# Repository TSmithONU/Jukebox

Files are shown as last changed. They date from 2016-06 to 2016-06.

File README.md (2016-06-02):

# Jukebox
This is the code and diagram to the Blue Jukebox located in COSI's Progress exhibit. Blue runs on an Arduino Mega and an Adafruit VS1053 Breakout board. This exhibit allows users to select a track number, and the corresponding track is played. To accomplish this, the mega reads in button presses from the button array on the front of the jukebox. The Mega then uses serial communication to begin playback of the track. Relay control was added to control the button latching and record spinning during playback. There is also a reset button that ends playback and resets the VS1053.

This software is designed to work with any Mega and can be costomized to playback any mp3 file.

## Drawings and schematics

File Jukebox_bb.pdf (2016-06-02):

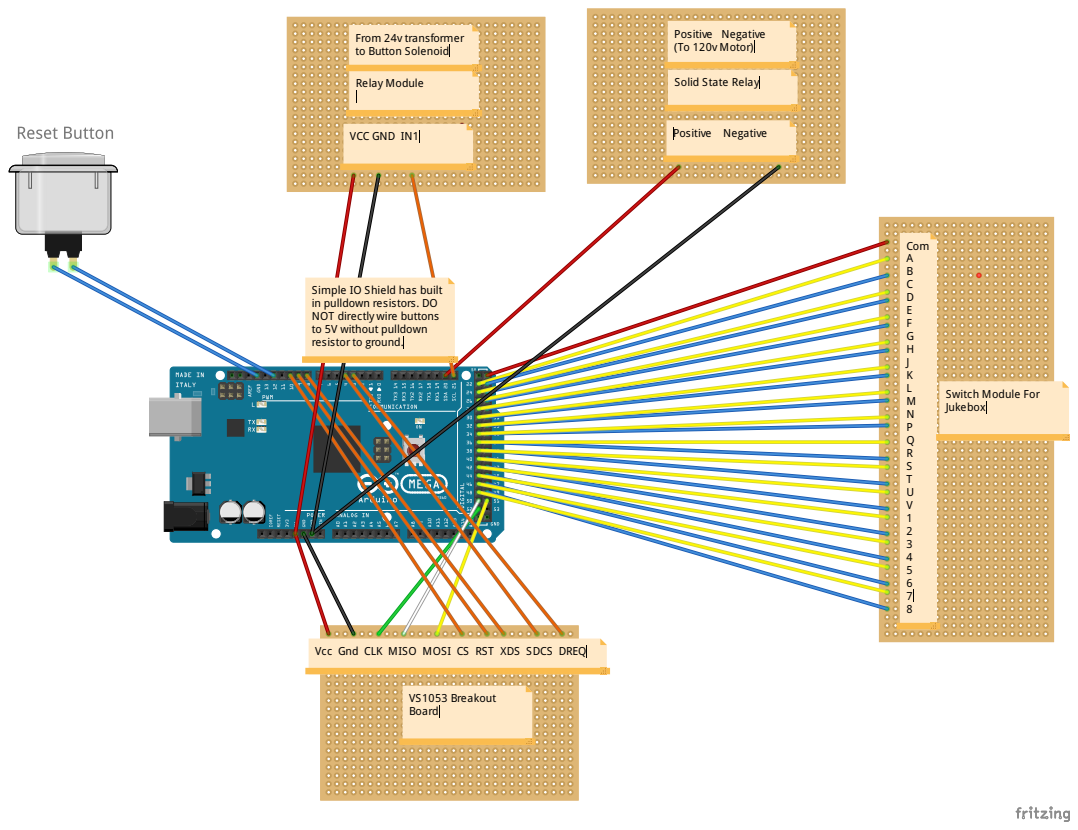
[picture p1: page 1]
Com A B C D E F G H J K L M N P Q R S T U V 1 2 3 4 5 6 7 8; VS1053 Breakout Board; Positive Negative; Positive Negative (To 120v Motor); Relay Module; VCC GND IN1

From 24v transformer
to Button Solenoid

Solid State Relay

Simple IO Shield has built
in pulldown resistors. DO
NOT directlywire buttons
to 5V without pulldown
resistorto ground.

Switch Module For
Jukebox

Vcc Gnd CLK MISO MOSI CS RST XDS SDCS DREQ

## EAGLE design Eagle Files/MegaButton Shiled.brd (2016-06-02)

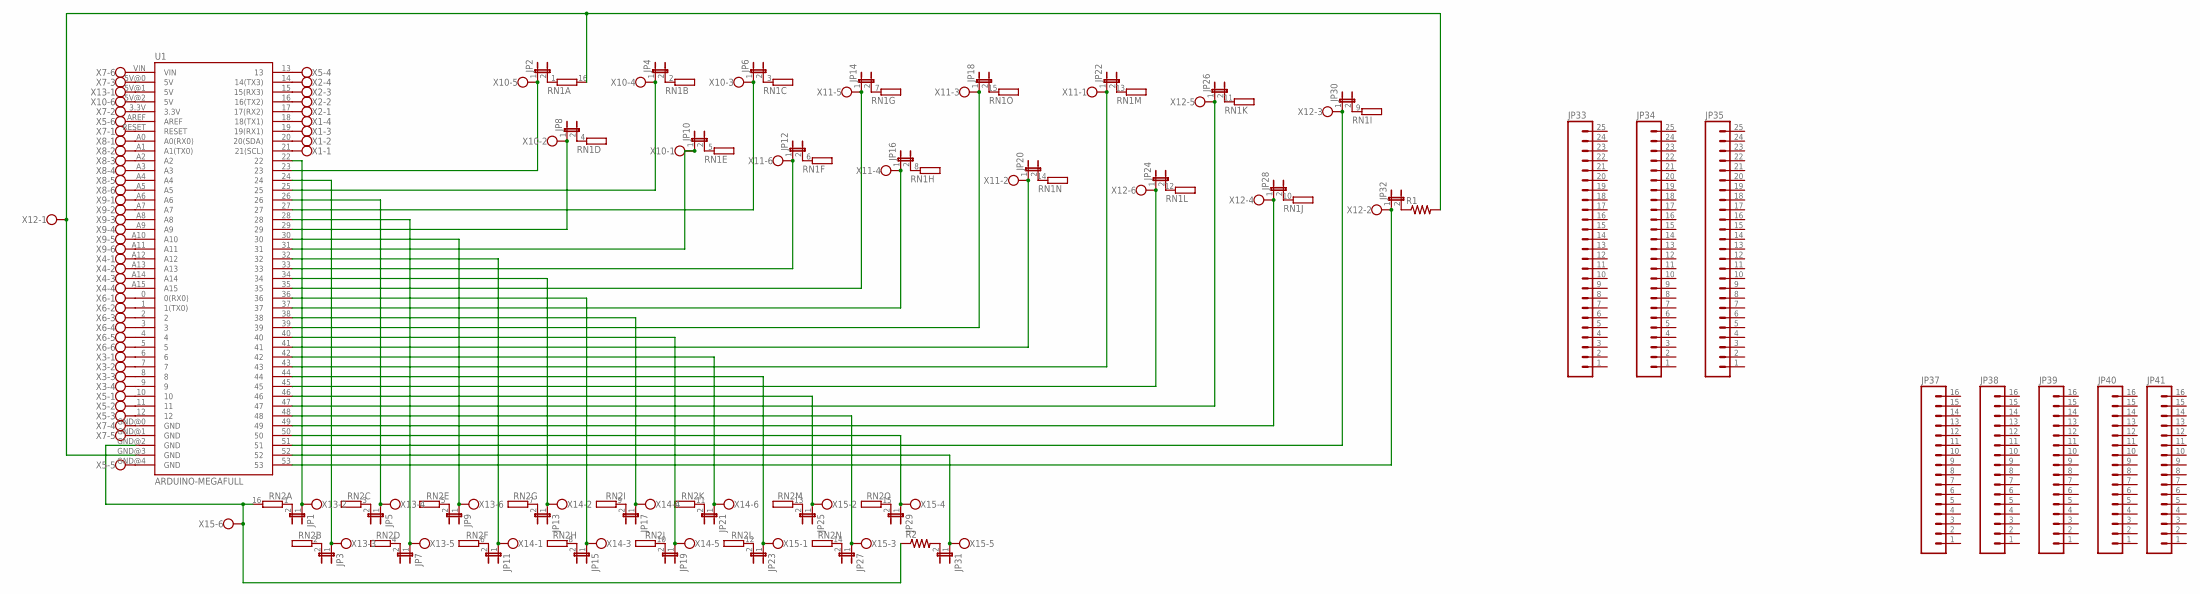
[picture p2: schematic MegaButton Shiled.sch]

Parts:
JP1, JP2, JP3, JP4, JP5, JP6, JP7, JP8, JP9, JP10, JP11, JP12, JP13, JP14, JP15, JP16, JP17, JP18, JP19, JP20, JP21, JP22, JP23, JP24, JP25, JP26, JP27, JP28, JP29, JP30, JP31, JP32: JP1E; JP1
JP33, JP34, JP35: M25PTH; 1X25
JP37, JP38, JP39, JP40, JP41: M16PTH; 1X16
R1, R2: R-US_0204/5; 0204/5
RN1, RN2: E15R; DIL16
U1: ARDUINO-MEGAFULL; ARDUINO_MEGA
X1, X2, X3, X4: W237-4
X5, X6, X7: W237-136
X8, X9, X10, X11, X12, X13, X14, X15: W237-6

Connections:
unnamed: U1.18 (18(TX1)), X1.4
unnamed: U1.19 (19(RX1)), X1.3
unnamed: U1.20 (20(SDA)), X1.2
unnamed: U1.21 (21(SCL)), X1.1
unnamed: U1.14 (14(TX3)), X2.4
unnamed: U1.15 (15(RX3)), X2.3
unnamed: U1.16 (16(TX2)), X2.2
unnamed: U1.17 (17(RX2)), X2.1
unnamed: U1.0 (0(RX0)), X6.1
unnamed: U1.1 (1(TX0)), X6.2
unnamed: U1.2, X6.3
unnamed: U1.3, X6.4
unnamed: U1.4, X6.5
unnamed: U1.5, X6.6
unnamed: U1.6, X3.1
unnamed: U1.7, X3.2
unnamed: U1.8, X3.3
unnamed: U1.9, X3.4
unnamed: U1.10, X5.1
unnamed: U1.11, X5.2
unnamed: U1.12, X5.3
unnamed: U1.13, X5.4
unnamed: U1.GND@4 (GND), X5.5
unnamed: U1.AREF, X5.6
unnamed: U1.RESET, X7.1
unnamed: U1.3.3V, X7.2
unnamed: U1.5V@0 (5V), X7.3
unnamed: U1.GND@0 (GND), X7.4
unnamed: U1.GND@1 (GND), X7.5
unnamed: U1.VIN, X7.6
unnamed: U1.A0 (A0(RX0)), X8.1
unnamed: U1.A1 (A1(TX0)), X8.2
unnamed: U1.A2, X8.3
unnamed: U1.A3, X8.4
unnamed: U1.A4, X8.5
unnamed: U1.A5, X8.6
unnamed: U1.A6, X9.1
unnamed: U1.A7, X9.2
unnamed: U1.A8, X9.3
unnamed: U1.A9, X9.4
unnamed: U1.A10, X9.5
unnamed: U1.A11, X9.6
unnamed: U1.A12, X4.1
unnamed: U1.A13, X4.2
unnamed: U1.A14, X4.3
unnamed: U1.A15, X4.4
unnamed: U1.5V@2 (5V), X10.6
unnamed: JP2.2, RN1.1
unnamed: JP2.1, U1.23, X10.5
unnamed: JP1.1, U1.22, X13.2
unnamed: JP4.1, U1.25, X10.4
unnamed: JP4.2, RN1.2 (1)
unnamed: JP6.1, U1.27, X10.3
unnamed: JP6.2, RN1.3 (1)
unnamed: JP8.1, U1.29, X10.2
unnamed: JP8.2, RN1.4 (1)
unnamed: JP10.1, U1.31, X10.1
unnamed: JP10.2, RN1.5 (1)
unnamed: JP12.1, U1.33, X11.6
unnamed: JP12.2, RN1.6 (1)
unnamed: JP14.2, RN1.7 (1)
unnamed: JP14.1, U1.35, X11.5
unnamed: JP16.2, RN1.8 (1)
unnamed: JP16.1, U1.37, X11.4
unnamed: JP18.2, RN1.15 (1)
unnamed: JP18.1, U1.39, X11.3
unnamed: JP20.1, U1.41, X11.2
unnamed: JP20.2, RN1.14 (1)
unnamed: JP22.1, U1.43, X11.1
unnamed: JP22.2, RN1.13 (1)
unnamed: JP24.1, U1.45, X12.6
unnamed: JP24.2, RN1.12 (1)
unnamed: JP26.2, RN1.11 (1)
unnamed: JP26.1, U1.47, X12.5
unnamed: JP28.2, RN1.10 (1)
unnamed: JP28.1, U1.49, X12.4
unnamed: JP30.2, RN1.9 (1)
unnamed: JP30.1, U1.51, X12.3
unnamed: JP32.1, U1.53, X12.2
unnamed: JP32.2, R1.1
unnamed: JP1.2, RN2.1
unnamed: U1.5V@1 (5V), X13.1
unnamed: JP3.2, RN2.2 (1)
unnamed: JP3.1, U1.24, X13.3
unnamed: JP5.2, RN2.3 (1)
unnamed: JP5.1, U1.26, X13.4
unnamed: JP7.2, RN2.4 (1)
unnamed: JP7.1, U1.28, X13.5
unnamed: JP9.2, RN2.5 (1)
unnamed: JP9.1, U1.30, X13.6
unnamed: JP11.2, RN2.6 (1)
unnamed: JP11.1, U1.32, X14.1
unnamed: JP13.2, RN2.7 (1)
unnamed: JP13.1, U1.34, X14.2
unnamed: JP15.2, RN2.8 (1)
unnamed: JP15.1, U1.36, X14.3
unnamed: JP17.2, RN2.9 (1)
unnamed: JP17.1, U1.38, X14.4
unnamed: JP19.2, RN2.10 (1)
unnamed: JP19.1, U1.40, X14.5
unnamed: JP21.2, RN2.11 (1)
unnamed: JP21.1, U1.42, X14.6
unnamed: JP23.2, RN2.12 (1)
unnamed: JP23.1, U1.44, X15.1
unnamed: JP25.2, RN2.13 (1)
unnamed: JP25.1, U1.46, X15.2
unnamed: R1.2, RN1.16 (2), U1.GND@3 (GND), X12.1
unnamed: JP27.2, RN2.14 (1)
unnamed: JP27.1, U1.48, X15.3
unnamed: JP29.2, RN2.15 (1)
unnamed: JP29.1, U1.50, X15.4
unnamed: JP31.2, R2.2
unnamed: JP31.1, U1.52, X15.5
unnamed: R2.1, RN2.16 (2), U1.GND@2 (GND), X15.6

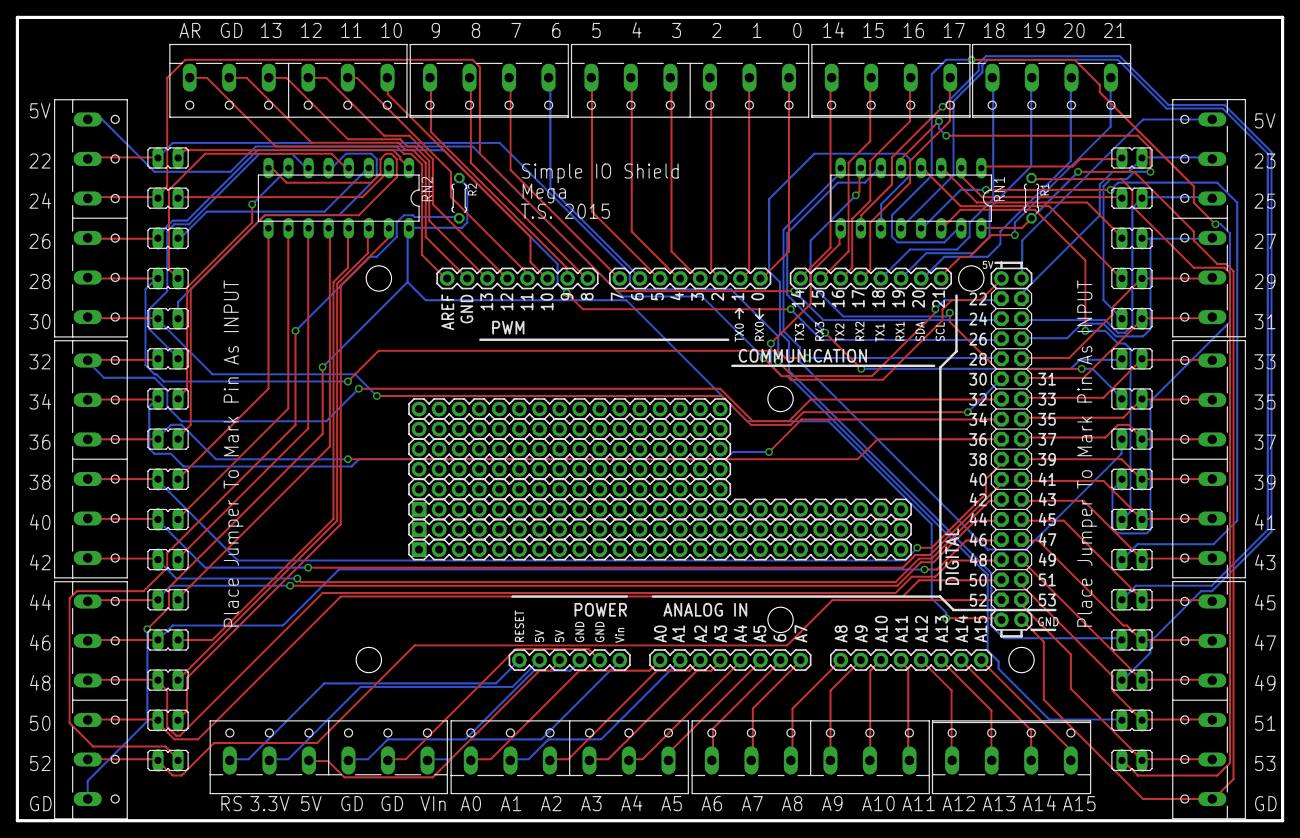
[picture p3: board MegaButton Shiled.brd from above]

Board: 2 copper layers, 160.0 x 101.6 mm, 60 parts (0 on the bottom side), 114 nets.

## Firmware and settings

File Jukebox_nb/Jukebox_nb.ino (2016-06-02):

#include <Bounce.h>

#include <Adafruit_VS1053.h>
#include <SPI.h>
#include <SD.h>


#define BREAKOUT_RESET 9
#define BREAKOUT_CS 10
#define BREAKOUT_DCS 8

#define CARDCS 4
#define DREQ 3

Adafruit_VS1053_FilePlayer musicPlayer = Adafruit_VS1053_FilePlayer(BREAKOUT_RESET, BREAKOUT_CS, BREAKOUT_DCS, DREQ, CARDCS);

const int A = 22;
const int B = 23;
const int C = 24;
const int D = 25;
const int E = 26;
const int F = 27;
const int G = 28;
const int H = 29;
const int J = 30;
const int K = 31;

const int L = 32;
const int M = 33;
const int N = 34;
const int P = 35;
const int Q = 36;
const int R = 37;
const int S = 38;
const int T = 39;
const int U = 40;
const int V = 41;

const int One = 42;
const int Two = 43;
const int Three = 44;
const int Four = 45;
const int Five = 46;
const int Six = 47;
const int Seven = 48;
const int Eight = 49;

const int Relay = 21;
const int Motor = 20;

const int Reset = 12;

const String MP3 = ".mp3";

Bounce RBbutton = Bounce (Reset, 10);
int counter = 0;


void setup() {
  // put your setup code here, to run once:
  pinMode(A, INPUT);
  pinMode(B, INPUT);
  pinMode(C, INPUT);
  pinMode(D, INPUT);
  pinMode(E, INPUT);
  pinMode(F, INPUT);
  pinMode(G, INPUT);
  pinMode(H, INPUT);
  pinMode(J, INPUT);
  pinMode(K, INPUT);

  pinMode(L, INPUT);
  pinMode(M, INPUT);
  pinMode(N, INPUT);
  pinMode(P, INPUT);
  pinMode(Q, INPUT);
  pinMode(R, INPUT);
  pinMode(S, INPUT);
  pinMode(T, INPUT);
  pinMode(U, INPUT);
  pinMode(V, INPUT);

  pinMode(One, INPUT);
  pinMode(Two, INPUT);
  pinMode(Three, INPUT);
  pinMode(Four, INPUT);
  pinMode(Five, INPUT);
  pinMode(Six, INPUT);
  pinMode(Seven, INPUT);
  pinMode(Eight, INPUT);

  pinMode(Reset, INPUT_PULLUP);

  pinMode(Relay, OUTPUT);
  digitalWrite(Relay, LOW);

  pinMode(Motor, OUTPUT);
  digitalWrite(Motor, HIGH);

  if (Serial) {
    Serial.begin(9600);
  }
  Serial.println("Initialize VS1053");
  if (!musicPlayer.begin()) {
    Serial.println("VS1053 NotFound");
    while (1);
  }
  Serial.println("VS1053 Initialized");
  SD.begin(CARDCS);
  Serial.println("SD Card Initialized");
  Serial.println("Jukebox Initialized");

  musicPlayer.setVolume(20, 20);

  musicPlayer.useInterrupt(VS1053_FILEPLAYER_PIN_INT);

}

void ResetButtons()
{
  delay(500);
  digitalWrite(Relay, HIGH);
  delay(250);
  digitalWrite(Relay, LOW);

}

void ButtonsOn() {
  delay(500);
  digitalWrite(Relay, LOW);
}

void ButtonsOff() {
  delay(500);
  digitalWrite(Relay, HIGH);

}

void PlayTrack (String TrackNumber)
{
  counter = 0;
  delay(500);
  char track2Play[7];
 (TrackNumber + MP3).toCharArray(track2Play, 7);
  Serial.println(track2Play);
  musicPlayer.startPlayingFile(track2Play);
  //Serial.println("Done Playing Track");
  //ButtonsOn();

}

void MotorOn() {
  digitalWrite(Motor, HIGH);
}

void MotorOff() {
  digitalWrite(Motor, LOW);
}

void loop() {
  // put your main code here, to run repeatedly:
  if ( musicPlayer.playingMusic) {
    MotorOn();
    if (digitalRead(Reset) == LOW) {
      musicPlayer.stopPlaying();
      Serial.println("ResetPressed");
      ButtonsOn();
      MotorOff();
      musicPlayer.softReset();
    }
  }
  else {
    //Serial.println("Track Finished");
    ButtonsOn();
    MotorOff();

    if (RBbutton.update()){
      if(RBbutton.fallingEdge()){
        counter+=1;
        if (counter <= 5){
          counter = 0;
          ButtonsOff();
          PlayTrack("Godzilla");
        }
      }
    }

    if (digitalRead(One) == HIGH)
    {
      Serial.println("Button 1 Pressed");
      if (digitalRead(A) == HIGH) {
        //Play Track 1
        Serial.println("Button A Pressed");
        Serial.println("Play Track A1");
        ButtonsOff();
        PlayTrack("A1");

      }
      if (digitalRead(B) == HIGH) {
        //Play Track 2
        Serial.println("Button B Pressed");
        Serial.println("Play Track B1");
        ButtonsOff();
        PlayTrack("B1");

      }
      if (digitalRead(C) == HIGH) {
        //Play Track 3
        Serial.println("Button C Pressed");
        Serial.println("Play Track C1");
        ButtonsOff();
        PlayTrack("C1");

      }
      if (digitalRead(D) == HIGH) {
        //Play Track 4
        Serial.println("Button D Pressed");
        Serial.println("Play Track D1");
        ButtonsOff();
        PlayTrack("D1");

      }
      if (digitalRead(E) == HIGH) {
        //Play Track 5
        Serial.println("Button E Pressed");
        Serial.println("Play Track E1");
        ButtonsOff();
        PlayTrack("E1");

      }
      if (digitalRead(F) == HIGH) {
        //Play Track 6
        Serial.println("Button F Pressed");
        Serial.println("Play Track F1");
        ButtonsOff();
        PlayTrack("F1");

      }
      if (digitalRead(G) == HIGH) {
        //Play Track 7
        Serial.println("Button G Pressed");
        Serial.println("Play Track G1");
        ButtonsOff();
        PlayTrack("G1");

      }
      if (digitalRead(H) == HIGH) {
        //Play Track 8
        Serial.println("Button H Pressed");
        Serial.println("Play Track H1");
        ButtonsOff();
        PlayTrack("H1");

      }
      if (digitalRead(J) == HIGH) {
        //Play Track 8
        Serial.println("Button J Pressed");
        Serial.println("Play Track J1");
        ButtonsOff();
        PlayTrack("J1");

      }
      if (digitalRead(K) == HIGH) {
        //Play Track 8
        Serial.println("Button K Pressed");
        Serial.println("Play Track K1");
        ButtonsOff();
        PlayTrack("K1");

      }
      if (digitalRead(L) == HIGH) {
        //Play Track 8
        Serial.println("Button L Pressed");
        Serial.println("Play Track L1");
        ButtonsOff();
        PlayTrack("L1");

      }
      if (digitalRead(M) == HIGH) {
        //Play Track 8
        Serial.println("Button M Pressed");
        Serial.println("Play Track M1");
        ButtonsOff();
        PlayTrack("M1");

      }
      if (digitalRead(N) == HIGH) {
        //Play Track 8
        Serial.println("Button N Pressed");
        Serial.println("Play Track N1");
        ButtonsOff();
        PlayTrack("N1");

      }
      if (digitalRead(P) == HIGH) {
        //Play Track 8
        Serial.println("Button P Pressed");
        Serial.println("Play Track P1");
        ButtonsOff();
        PlayTrack("P1");

      }
      if (digitalRead(Q) == HIGH) {
        //Play Track 8
        Serial.println("Button Q Pressed");
        Serial.println("Play Track Q1");
        ButtonsOff();
        PlayTrack("Q1");

      }
      if (digitalRead(R) == HIGH) {
        //Play Track 8
        Serial.println("Button R Pressed");
        Serial.println("Play Track R1");
        ButtonsOff();
        PlayTrack("R1");

      }
      if (digitalRead(S) == HIGH) {
        //Play Track 8
        Serial.println("Button S Pressed");
        Serial.println("Play Track S1");
        ButtonsOff();
        PlayTrack("S1");

      }
      if (digitalRead(T) == HIGH) {
        //Play Track 8
        Serial.println("Button T Pressed");
        Serial.println("Play Track T1");
        ButtonsOff();
        PlayTrack("T1");

      }      if (digitalRead(U) == HIGH) {
        //Play Track 8
        Serial.println("Button U Pressed");
        Serial.println("Play Track U1");
        ButtonsOff();
        PlayTrack("U1");

      }
      if (digitalRead(V) == HIGH) {
        //Play Track 8
        Serial.println("Button V Pressed");
        Serial.println("Play Track V1");
        ButtonsOff();
        PlayTrack("V1");

      }
    }

    if (digitalRead(Two) == HIGH)
    {
      Serial.println("Button B Pressed");
      if (digitalRead(A) == HIGH) {
        //Play Track 1
        Serial.println("Button 1 Pressed");
        Serial.println("Play Track 1");
        ButtonsOff();
        PlayTrack("A2");

      }
      if (digitalRead(B) == HIGH) {
        //Play Track 2
        Serial.println("Button 2 Pressed");
        Serial.println("Play Track 2");
        ButtonsOff();
        PlayTrack("B2");

      }
      if (digitalRead(C) == HIGH) {
        //Play Track 3
        Serial.println("Button 3 Pressed");
        Serial.println("Play Track 3");
        ButtonsOff();
        PlayTrack("C2");

      }
      if (digitalRead(D) == HIGH) {
        //Play Track 4
        Serial.println("Button 4 Pressed");
        Serial.println("Play Track 4");
        ButtonsOff();
        PlayTrack("D2");

      }
      if (digitalRead(E) == HIGH) {
        //Play Track 5
        Serial.println("Button 5 Pressed");
        Serial.println("Play Track 5");
        ButtonsOff();
        PlayTrack("E2");

      }
      if (digitalRead(F) == HIGH) {
        //Play Track 6
        Serial.println("Button 6 Pressed");
        Serial.println("Play Track 6");
        ButtonsOff();
        PlayTrack("F2");

      }
      if (digitalRead(G) == HIGH) {
        //Play Track 7
        Serial.println("Button 7 Pressed");
        Serial.println("Play Track 7");
        ButtonsOff();
        PlayTrack("G2");

      }
      if (digitalRead(H) == HIGH) {
        //Play Track 8
        Serial.println("Button 8 Pressed");
        Serial.println("Play Track 8");
        ButtonsOff();
        PlayTrack("H2");

      }
      if (digitalRead(J) == HIGH) {
        //Play Track 8
        Serial.println("Button 8 Pressed");
        Serial.println("Play Track 8");
        ButtonsOff();
        PlayTrack("J2");

      }
      if (digitalRead(K) == HIGH) {
        //Play Track 8
        Serial.println("Button 8 Pressed");
        Serial.println("Play Track 8");
        ButtonsOff();
        PlayTrack("K2");

      }
      if (digitalRead(L) == HIGH) {
        //Play Track 8
        Serial.println("Button 8 Pressed");
        Serial.println("Play Track 8");
        ButtonsOff();
        PlayTrack("L2");

      }
      if (digitalRead(M) == HIGH) {
        //Play Track 8
        Serial.println("Button 8 Pressed");
        Serial.println("Play Track 8");
        ButtonsOff();
        PlayTrack("M2");

      }
      if (digitalRead(N) == HIGH) {
        //Play Track 8
        Serial.println("Button 8 Pressed");
        Serial.println("Play Track 8");
        ButtonsOff();
        PlayTrack("N2");

      }
      if (digitalRead(P) == HIGH) {
        //Play Track 8
        Serial.println("Button 8 Pressed");
        Serial.println("Play Track 8");
        ButtonsOff();
        PlayTrack("P2");

      }
      if (digitalRead(Q) == HIGH) {
        //Play Track 8
        Serial.println("Button 8 Pressed");
        Serial.println("Play Track 8");
        ButtonsOff();
        PlayTrack("Q2");

      }
      if (digitalRead(R) == HIGH) {
        //Play Track 8
        Serial.println("Button 8 Pressed");
        Serial.println("Play Track 8");
        ButtonsOff();
        PlayTrack("R2");

      }
      if (digitalRead(S) == HIGH) {
        //Play Track 8
        Serial.println("Button 8 Pressed");
        Serial.println("Play Track 8");
        ButtonsOff();
        PlayTrack("S2");

      }
      if (digitalRead(T) == HIGH) {
        //Play Track 8
        Serial.println("Button 8 Pressed");
        Serial.println("Play Track 8");
        ButtonsOff();
        PlayTrack("T2");

      }      if (digitalRead(U) == HIGH) {
        //Play Track 8
        Serial.println("Button 8 Pressed");
        Serial.println("Play Track 8");
        ButtonsOff();
        PlayTrack("U2");

      }
      if (digitalRead(V) == HIGH) {
        //Play Track 8
        Serial.println("Button 8 Pressed");
        Serial.println("Play Track 8");
        ButtonsOff();
        PlayTrack("V2");
      }
    }

    if (digitalRead(Three) == HIGH)
    {
      Serial.println("Button C Pressed");
      if (digitalRead(A) == HIGH) {
        //Play Track 1
        Serial.println("Button 1 Pressed");
        Serial.println("Play Track 1");
        ButtonsOff();
        PlayTrack("A3");

      }
      if (digitalRead(B) == HIGH) {
        //Play Track 2
        Serial.println("Button 2 Pressed");
        Serial.println("Play Track 2");
        ButtonsOff();
        PlayTrack("B3");

      }
      if (digitalRead(C) == HIGH) {
        //Play Track 3
        Serial.println("Button 3 Pressed");
        Serial.println("Play Track 3");
        ButtonsOff();
        PlayTrack("C3");

      }
      if (digitalRead(D) == HIGH) {
        //Play Track 4
        Serial.println("Button 4 Pressed");
        Serial.println("Play Track 4");
        ButtonsOff();
        PlayTrack("D3");

      }
      if (digitalRead(E) == HIGH) {
        //Play Track 5
        Serial.println("Button 5 Pressed");
        Serial.println("Play Track 5");
        ButtonsOff();
        PlayTrack("E3");

      }
      if (digitalRead(F) == HIGH) {
        //Play Track 6
        Serial.println("Button 6 Pressed");
        Serial.println("Play Track 6");
        ButtonsOff();
        PlayTrack("F3");

      }
      if (digitalRead(G) == HIGH) {
        //Play Track 7
        Serial.println("Button 7 Pressed");
        Serial.println("Play Track 7");
        ButtonsOff();
        PlayTrack("G3");

      }
      if (digitalRead(H) == HIGH) {
        //Play Track 8
        Serial.println("Button 8 Pressed");
        Serial.println("Play Track 8");
        ButtonsOff();
        PlayTrack("H3");

      }
      if (digitalRead(J) == HIGH) {
        //Play Track 8
        Serial.println("Button 8 Pressed");
        Serial.println("Play Track 8");
        ButtonsOff();
        PlayTrack("J3");

      }
      if (digitalRead(K) == HIGH) {
        //Play Track 8
        Serial.println("Button 8 Pressed");
        Serial.println("Play Track 8");
        ButtonsOff();
        PlayTrack("K3");

      }
      if (digitalRead(L) == HIGH) {
        //Play Track 8
        Serial.println("Button 8 Pressed");
        Serial.println("Play Track 8");
        ButtonsOff();
        PlayTrack("L3");

      }
      if (digitalRead(M) == HIGH) {
        //Play Track 8
        Serial.println("Button 8 Pressed");
        Serial.println("Play Track 8");
        ButtonsOff();
        PlayTrack("M3");

      }
      if (digitalRead(N) == HIGH) {
        //Play Track 8
        Serial.println("Button 8 Pressed");
        Serial.println("Play Track 8");
        ButtonsOff();
        PlayTrack("N3");

      }
      if (digitalRead(P) == HIGH) {
        //Play Track 8
        Serial.println("Button 8 Pressed");
        Serial.println("Play Track 8");
        ButtonsOff();
        PlayTrack("P3");

      }
      if (digitalRead(Q) == HIGH) {
        //Play Track 8
        Serial.println("Button 8 Pressed");
        Serial.println("Play Track 8");
        ButtonsOff();
        PlayTrack("Q3");

      }
      if (digitalRead(R) == HIGH) {
        //Play Track 8
        Serial.println("Button 8 Pressed");
        Serial.println("Play Track 8");
        ButtonsOff();
        PlayTrack("R3");

      }
      if (digitalRead(S) == HIGH) {
        //Play Track 8
        Serial.println("Button 8 Pressed");
        Serial.println("Play Track 8");
        ButtonsOff();
        PlayTrack("S3");

      }
      if (digitalRead(T) == HIGH) {
        //Play Track 8
        Serial.println("Button 8 Pressed");
        Serial.println("Play Track 8");
        ButtonsOff();
        PlayTrack("T3");

      }      if (digitalRead(U) == HIGH) {
        //Play Track 8
        Serial.println("Button 8 Pressed");
        Serial.println("Play Track 8");
        ButtonsOff();
        PlayTrack("U3");

      }
      if (digitalRead(V) == HIGH) {
        //Play Track 8
        Serial.println("Button 8 Pressed");
        Serial.println("Play Track 8");
        ButtonsOff();
        PlayTrack("V3");
      }
    }
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

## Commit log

2016-06-02 Upload Code
    Initial Upload to github
    [MegaButton Shiled.brd, MegaButton Shiled.sch]
2016-06-02 Add Schematic
    Uploading wiring schematic of jukebox

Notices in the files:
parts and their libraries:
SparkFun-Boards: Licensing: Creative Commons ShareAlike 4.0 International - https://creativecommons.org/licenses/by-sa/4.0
